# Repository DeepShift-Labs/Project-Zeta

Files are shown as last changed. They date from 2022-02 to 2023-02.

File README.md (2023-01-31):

# Project-Zeta
Github BannerZeta

***This repository is incomplete and under development. There may be mistakes or missing information. Please bear with it. ANY QUESTIONS YOU HAVE CAN BE ASKED IN THE DISCUSSIONS AND ISSUES. Thank you for cooperating.***

The goal of Project Zeta is to develop the world's first General Intelligence. Yes, a robot uprising is coming. We, at Project Zeta, are determined to develop a reliable platform to collect, process, and train data to develop a human-like intelligence. This is possible by using a custom-built, biomimetic, robot dog, with tons of sensors for environmental perception. To learn more about the AI itself, look at this repo:

Readme Card (https://github.com/DeepShift-Labs/MAGIST-Algorithm)

## The Idea
We are making a versatile and cost-effective development platform to collect data. This will allow us to not only collect data but also implement the general intelligence into the robot. In fact, our project MAGIST has achieved General Intelligence! [Check out our other repositories to learn more.](https://github.com/DeepShift-Labs) If you want to brainstorm ideas with us and get the latest updates, make a contribution to our OpenCollective! Check the Links section for the link!

## Setup and Assembly
All assembly instructions will be provided on the Wiki page. The ROS Stack currently requires the "ros-noetic-desktop-full" which has dependencies for around 200 packages. This will only currently work on multi-core PCs and not on Raspberry Pi. This will eventually be optimized to compile on ARM CPUs. More information will be provided on compilation and setup when the code is functional.

## Open Source
The overall point of this project is to make it as open-source as possible. My code is open source, the motors I used also provide their code and all the information to recreate them, and my 3D model of the dog will be on Thingiverse soon. 

- Motors: Lewansoul LX-16A; https://www.hiwonder.com/store/learn/26.html; https://www.amazon.com/Hiwonder-LX-16A-Robotic-Controller-Control/dp/B073XY5NT1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
- Gyroscope: https://www.amazon.com/HiLetgo-MPU-6050-Accelerometer-Gyroscope-Converter/dp/B00LP25V1A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
- Arduino: https://store-usa.arduino.cc/collections/most-popular/products/arduino-mega-2560-rev3

***Note, that the AI might be under a different license. Treat the AI and the robot dog as 2 separate projects.***

### Main Tools
- 3D Printer: https://www.amazon.com/LOTMAXX-Certified-Removable-235x235x280mm-9-25x9-25x11-02inch/dp/B081N6CRVP

## The Team

#### Krishna:
I am a robotics hobbyist, enthusiast, and creator. I have been in robotics for the past 6 years and I have experience in various fields of study. I have tremendous experience in Python, C, Tensorflow, ROS, as well as electronics, 3D Printing, and much more.

## Our AI Project: MAGIST
Readme Card (https://github.com/DeepShift-Labs/MAGIST-Algorithm)

# Links
- OpenCollective: https://opencollective.com/deepshift-labs
- Website: https://deepshift.dev
- Medium: https://deepshiftlabs.medium.com/
- YouTube: https://www.youtube.com/channel/UC6nu2aGbAEX3yy5b0W9GBIg

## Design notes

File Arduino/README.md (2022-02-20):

# Arduino
This contains a complete Arduino code running on the Arduino Mega 2560. Later, I will add hardware and software requirments and compatibility instructions. 

BTW, don't worry about the temp.h file. It is just in place until I put some useless reference code. Don't mind it.

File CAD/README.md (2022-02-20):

# CAD
All the CAD drawing in all te popular formats will be provided. If you are looking for the Gazebo URDF, they are provided in a folder called zeta_description in the ROS_Stack.

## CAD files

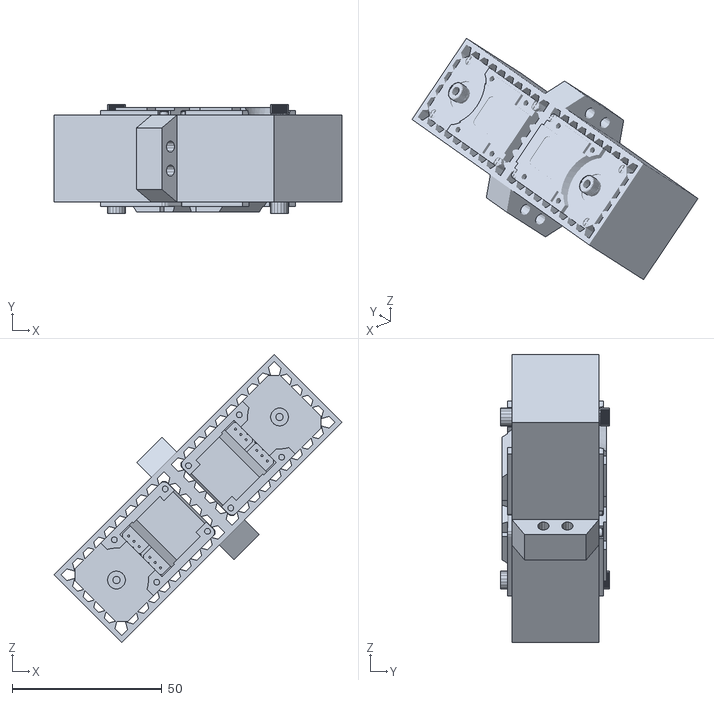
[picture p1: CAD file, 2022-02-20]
ROS_Stack/src/zeta_description/meshes/BR_motor_block_1.stl
96.2 x 36.2 x 96.2

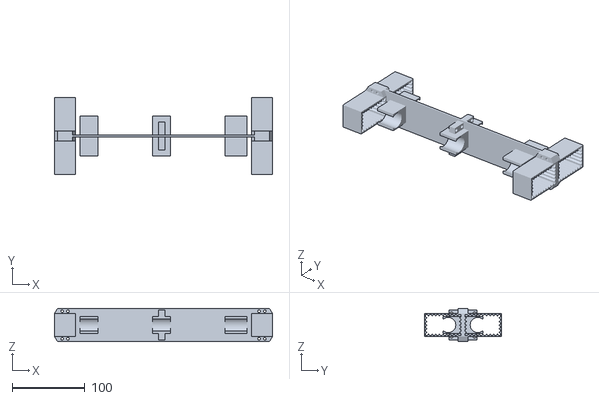
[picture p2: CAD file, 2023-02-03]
ROS_Stack/src/zeta_urdf_description/meshes/base_link.stl
300.0 x 106.4 x 46.0

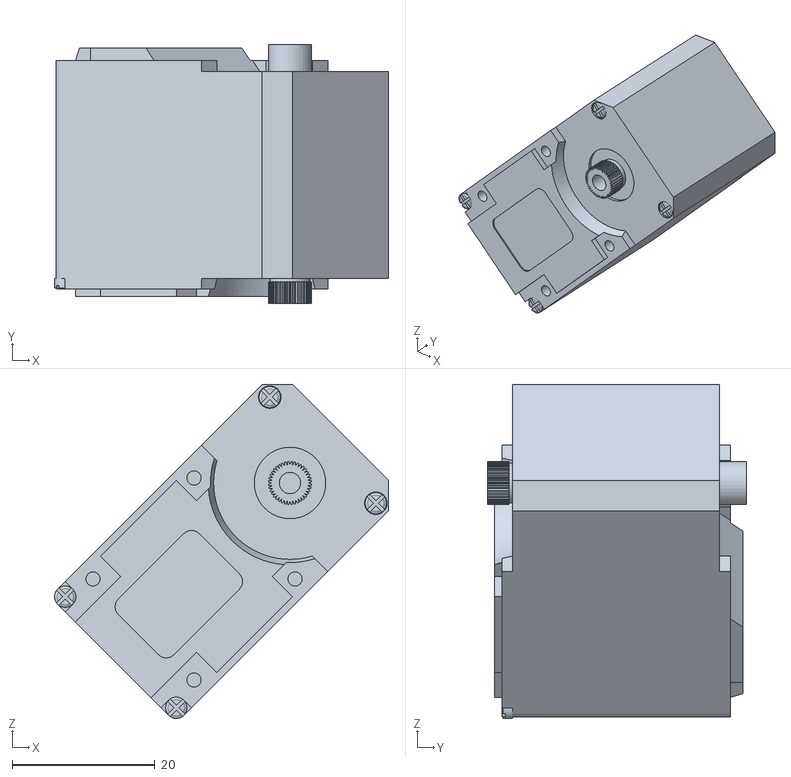
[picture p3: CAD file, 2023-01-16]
URDF/Raw_URDF/zeta_urdf_description_ros1/meshes/FL_2_Motor_1.stl
46.8 x 36.2 x 46.8

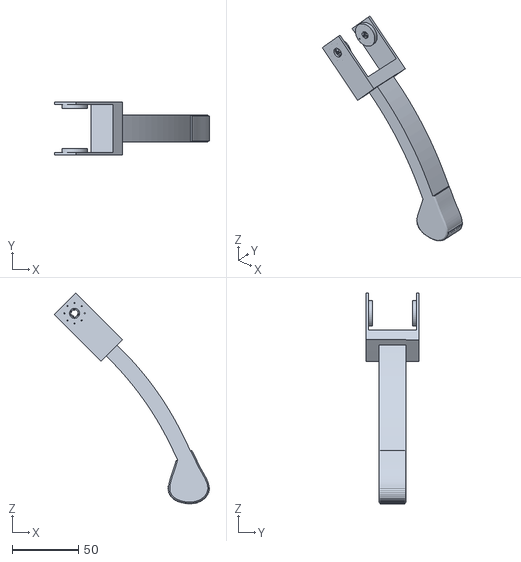
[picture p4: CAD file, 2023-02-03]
URDF/Tuned_URDF/zeta_urdf_description/meshes/BR_Foot_1.stl
117.4 x 40.2 x 159.4

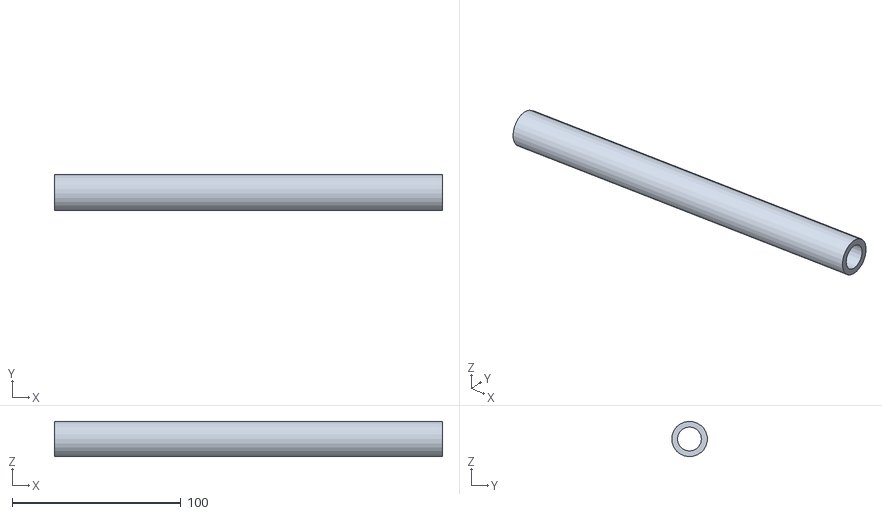
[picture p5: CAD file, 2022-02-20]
ROS_Stack/src/zeta_description/meshes/L_Pipe_1.stl
229.9 x 21.0 x 20.9

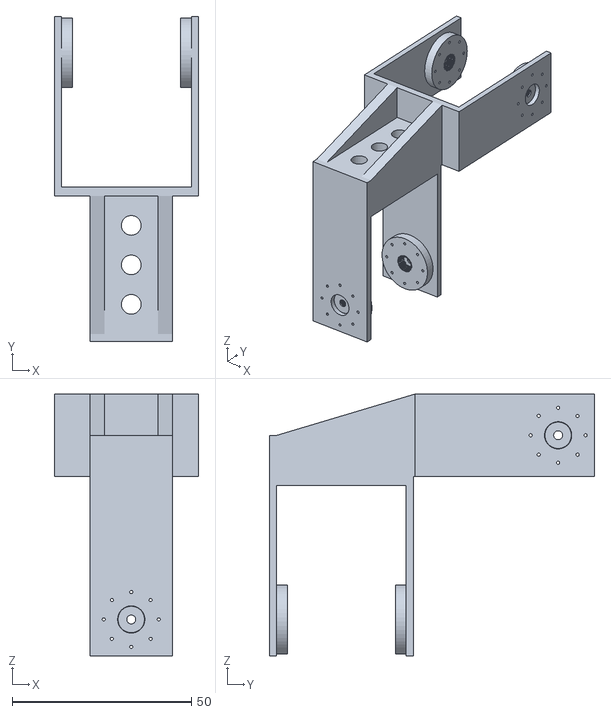
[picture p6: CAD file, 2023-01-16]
URDF/Raw_URDF/zeta_urdf_description_ros1/meshes/FR_Top_Bracket_1.stl
40.2 x 90.6 x 73.0

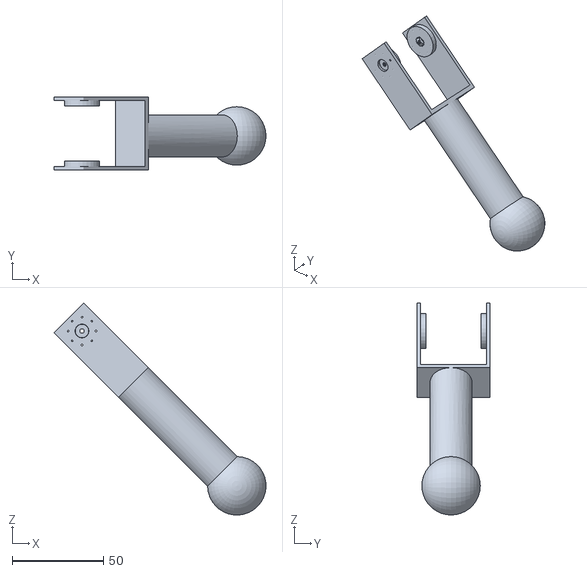
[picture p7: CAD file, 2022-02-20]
ROS_Stack/src/zeta_description/meshes/FL_foot_1.stl
116.0 x 40.2 x 116.0

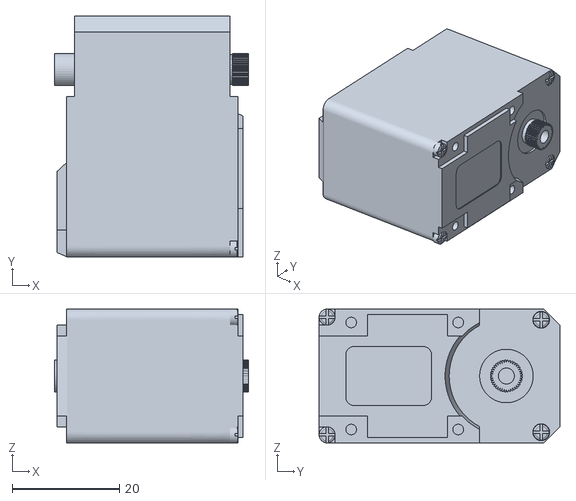
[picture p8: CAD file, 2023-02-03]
ROS_Stack/src/zeta_urdf_description/meshes/FL_3_Motor_1.stl
36.2 x 45.0 x 25.0

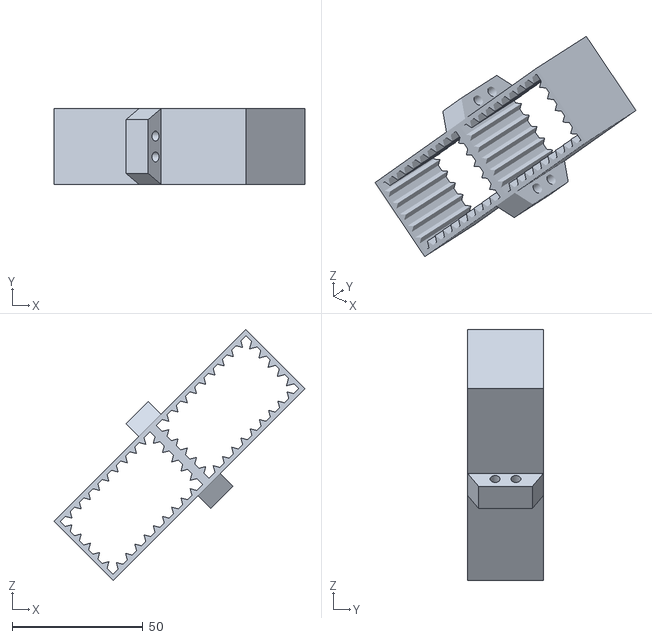
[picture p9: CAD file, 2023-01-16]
URDF/Raw_URDF/zeta_urdf_description_ros2/meshes/FL_Dual_Motor_Mount_1.stl
96.2 x 29.0 x 96.2

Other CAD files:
ROS_Stack/src/zeta_urdf_description/meshes/FR_Foot_1.stl
URDF/Tuned_URDF/zeta_urdf_description/meshes/BR_1_Motor_1.stl
URDF/Raw_URDF/zeta_urdf_description_ros1/meshes/base_link.stl
URDF/Tuned_URDF/zeta_urdf_description/meshes/BR_Top_Bracket_1.stl
ROS_Stack/src/zeta_description/meshes/FL_motor_block_1.stl
ROS_Stack/src/zeta_urdf_description/meshes/BR_Top_Bracket_1.stl
URDF/Raw_URDF/zeta_urdf_description_ros1/meshes/BL_Foot_1.stl
CAD/URDF/zeta_urdf_description/meshes/BL_1_Motor_1.stl
CAD/URDF/zeta_urdf_description/meshes/BL_2_Motor_1.stl
CAD/URDF/zeta_urdf_description/meshes/BL_3_Motor_1.stl
CAD/URDF/zeta_urdf_description/meshes/BL_Dual_Motor_Mount_1.stl
CAD/URDF/zeta_urdf_description/meshes/BL_Foot_1.stl
CAD/URDF/zeta_urdf_description/meshes/BL_Top_Bracket_1.stl
CAD/URDF/zeta_urdf_description/meshes/BR_1_Motor_1.stl
CAD/URDF/zeta_urdf_description/meshes/BR_2_Motor_1.stl
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

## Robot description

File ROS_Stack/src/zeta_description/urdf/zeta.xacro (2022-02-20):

<?xml version="1.0" ?>
<robot name="zeta" xmlns:xacro="http://www.ros.org/wiki/xacro">

<xacro:include filename="$(find zeta_description)/urdf/materials.xacro" />
<xacro:include filename="$(find zeta_description)/urdf/zeta.trans" />

<xacro:include filename="$(find zeta_description)/gazebo/zeta_materials.gazebo" />
<xacro:include filename="$(find zeta_description)/gazebo/zeta_physics.gazebo" />
<xacro:include filename="$(find zeta_description)/gazebo/zeta_plugins.gazebo" />

<link name="base_link">
  <inertial>
    <origin rpy="0 0 0" xyz="-0.14461409332930716 0.0883518788335936 0.2064875843501072"/>
    <mass value="0.26109888559714134"/>
    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
  </inertial>
  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
</link>

<link name="BL_foot_1">
  <inertial>
    <origin rpy="0 0 0" xyz="0.05644955069451385 -0.01619715461445445 -0.056449524198164465"/>
    <mass value="0.050254366168808934"/>
    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
  </inertial>
  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
</link>

<link name="BL_motor_block_1">
  <inertial>
    <origin rpy="0 0 0" xyz="-0.027223152863659228 -0.014672109847305964 -0.02722359848924935"/>
    <mass value="0.08833659369300421"/>
    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
  </inertial>
  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
</link>

<link name="BL_top_1">
  <inertial>
    <origin rpy="0 0 0" xyz="0.016013586630673704 0.047570667286835455 -0.011363799013344889"/>
    <mass value="0.026371988478748627"/>
    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
  </inertial>
  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
</link>

<link name="BR_foot_1">
  <inertial>
    <origin rpy="0 0 0" xyz="0.0564495506979143 0.016196912277002512 -0.05644952420106039"/>
    <mass value="0.050254366173962006"/>
    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
  </inertial>
  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
</link>

<link name="BR_motor_block_1">
  <inertial>
    <origin rpy="0 0 0" xyz="-0.027223152862709155 0.014671867515031146 -0.02722359848963765"/>
    <mass value="0.08833659369327077"/>
    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
  </inertial>
  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
</link>

<link name="BR_top_1">
  <inertial>
    <origin rpy="0 0 0" xyz="0.016013586630497123 -0.04757090961961194 -0.011363799013237114"/>
    <mass value="0.026371988478739887"/>
    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
  </inertial>
  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
</link>

<link name="FR_top_1">
  <inertial>
    <origin rpy="0 0 0" xyz="0.016013586630579342 -0.04757090961960731 -0.011363799013341308"/>
    <mass value="0.026371988478748786"/>
    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
  </inertial>
  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
</link>

<link name="FL_foot_1">
  <inertial>
    <origin rpy="0 0 0" xyz="0.05644955069451409 -0.016197154614456588 -0.056449524198166345"/>
    <mass value="0.0502543661688089"/>
    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
  </inertial>
  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
</link>

<link name="FL_motor_block_1">
  <inertial>
    <origin rpy="0 0 0" xyz="-0.02718553583877841 -0.014671926830458815 -0.027187005197919556"/>
    <mass value="0.08843072327026845"/>
    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
  </inertial>
  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
</link>

<link name="FL_top_1">
  <inertial>
    <origin rpy="0 0 0" xyz="0.0160135866305811 0.04757066728683562 -0.011363799013343834"/>
    <mass value="0.02637198847874842"/>
    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
  </inertial>
  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
</link>

<link name="R_Pipe_1">
  <inertial>
    <origin rpy="0 0 0" xyz="0.1149254583128192 -0.00019701609423813937 -3.9498945669791397e-08"/>
    <mass value="0.06072232848588734"/>
    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
  </inertial>
  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
</link>

<link name="L_Pipe_1">
  <inertial>
    <origin rpy="0 0 0" xyz="0.11492545831281933 0.00019677376152678339 -3.949894572530255e-08"/>
    <mass value="0.06072232848588743"/>
    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
  </inertial>
  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
</link>

<link name="FR_foot_1">
  <inertial>
    <origin rpy="0 0 0" xyz="0.05644955069791327 0.01619691227700047 -0.05644952420106501"/>
    <mass value="0.05025436617396211"/>
    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
  </inertial>
  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
</link>

<link name="FR_motor_block_1">
  <inertial>
    <origin rpy="0 0 0" xyz="-0.027185535838667285 0.014671684498179257 -0.0271870051983098"/>
    <mass value="0.0884307232705417"/>
    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
  </inertial>
  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
</link>

<joint name="Rev46" type="continuous">
  <origin rpy="0 0 0" xyz="-0.054447 0.0 -0.054447"/>
  <parent link="BL_motor_block_1"/>
  <child link="BL_foot_1"/>
  <axis xyz="0.0 1.0 -0.0"/>
</joint>

<joint name="Rev47" type="continuous">
  <origin rpy="0 0 0" xyz="0.0164 0.075469 -0.051319"/>
  <parent link="BL_top_1"/>
  <child link="BL_motor_block_1"/>
  <axis xyz="0.0 -1.0 0.0"/>
</joint>

<joint name="Rev48" type="continuous">
  <origin rpy="0 0 0" xyz="-0.295505 0.128052 0.206491"/>
  <parent link="base_link"/>
  <child link="BL_top_1"/>
  <axis xyz="1.0 -0.0 -0.0"/>
</joint>

<joint name="Rev49" type="continuous">
  <origin rpy="0 0 0" xyz="-0.054447 0.0 -0.054447"/>
  <parent link="BR_motor_block_1"/>
  <child link="BR_foot_1"/>
  <axis xyz="-0.0 -1.0 0.0"/>
</joint>

<joint name="Rev50" type="continuous">
  <origin rpy="0 0 0" xyz="0.0164 -0.075469 -0.051319"/>
  <parent link="BR_top_1"/>
  <child link="BR_motor_block_1"/>
  <axis xyz="-0.0 -1.0 0.0"/>
</joint>

<joint name="Rev51" type="continuous">
  <origin rpy="0 0 0" xyz="-0.295505 0.048652 0.206491"/>
  <parent link="base_link"/>
  <child link="BR_top_1"/>
  <axis xyz="-1.0 0.0 0.0"/>
</joint>

<joint name="Rev54" type="continuous">
  <origin rpy="0 0 0" xyz="-0.024505 0.048652 0.206491"/>
  <parent link="base_link"/>
  <child link="FR_top_1"/>
  <axis xyz="-1.0 0.0 0.0"/>
</joint>

<joint name="Rev55" type="continuous">
  <origin rpy="0 0 0" xyz="-0.054447 0.0 -0.054447"/>
  <parent link="FL_motor_block_1"/>
  <child link="FL_foot_1"/>
  <axis xyz="0.0 -1.0 -0.0"/>
</joint>

<joint name="Rev56" type="continuous">
  <origin rpy="0 0 0" xyz="0.0164 0.075469 -0.051319"/>
  <parent link="FL_top_1"/>
  <child link="FL_motor_block_1"/>
  <axis xyz="0.0 -1.0 0.0"/>
</joint>

<joint name="Rev57" type="continuous">
  <origin rpy="0 0 0" xyz="-0.024505 0.128052 0.206491"/>
  <parent link="base_link"/>
  <child link="FL_top_1"/>
  <axis xyz="1.0 -0.0 -0.0"/>
</joint>

<joint name="Rigid58" type="fixed">
  <origin rpy="0 0 0" xyz="-0.260605 0.067967 0.206491"/>
  <parent link="base_link"/>
  <child link="R_Pipe_1"/>
</joint>

<joint name="Rigid59" type="fixed">
  <origin rpy="0 0 0" xyz="-0.260605 0.108737 0.206491"/>
  <parent link="base_link"/>
  <child link="L_Pipe_1"/>
</joint>

<joint name="Rev61" type="continuous">
  <origin rpy="0 0 0" xyz="-0.054447 0.0 -0.054447"/>
  <parent link="FR_motor_block_1"/>
  <child link="FR_foot_1"/>
  <axis xyz="-0.0 -1.0 0.0"/>
</joint>

<joint name="Rev62" type="continuous">
  <origin rpy="0 0 0" xyz="0.0164 -0.075469 -0.051319"/>
  <parent link="FR_top_1"/>
  <child link="FR_motor_block_1"/>
  <axis xyz="-0.0 -1.0 0.0"/>
</joint>

</robot>

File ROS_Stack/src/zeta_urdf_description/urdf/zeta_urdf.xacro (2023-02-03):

<?xml version="1.0" ?>
<robot name="zeta_urdf" xmlns:xacro="http://www.ros.org/wiki/xacro">

<xacro:include filename="$(find zeta_urdf_description)/urdf/materials.xacro" />
<xacro:include filename="$(find zeta_urdf_description)/urdf/zeta_urdf.trans" />
<xacro:include filename="$(find zeta_urdf_description)/urdf/zeta_urdf.gazebo" />

<link name="dummy">
   </link>

<link name="base_link">
  <inertial>
    <origin xyz="-0.006887732149199177 0.005649968016768892 0.20576830530971255" rpy="0 0 0"/>
    <mass value="0.13102657430451126"/>
    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
  </inertial>
  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
</link>

  <joint name="dummy_joint" type="fixed">
     <parent link="dummy"/>
     <child link="base_link"/>
   </joint>

<link name="FL_Foot_1">
  <inertial>
    <origin xyz="0.05628492645882191 -0.015254964193953696 -0.06460044311982074" rpy="0 0 0"/>
    <mass value="0.10306892931910153"/>
    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
  </inertial>
  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
</link>

<link name="FL_Dual_Motor_Mount_1">
  <inertial>
    <origin xyz="-0.0178564728403042 -8.413959165509688e-08 -0.01785834127628591" rpy="0 0 0"/>
    <mass value="0.023417593270727483"/>
    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
  </inertial>
  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
</link>

<link name="FL_Top_Bracket_1">
  <inertial>
    <origin xyz="0.015262819778462638 0.04757075647002189 -0.011363296083874236" rpy="0 0 0"/>
    <mass value="0.026371988478740775"/>
    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
  </inertial>
  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
</link>

<link name="FR_Top_Bracket_1">
  <inertial>
    <origin xyz="0.015262819778460085 -0.04757082043654881 -0.011363296083875513" rpy="0 0 0"/>
    <mass value="0.02637198847874129"/>
    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
  </inertial>
  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
</link>

<link name="FR_3_Motor_1">
  <inertial>
    <origin xyz="0.0002325331004134623 0.0038811305183252993 5.631524657712106e-08" rpy="0 0 0"/>
    <mass value="0.09250068837166636"/>
    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
  </inertial>
  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
</link>

<link name="Pipe_R_1">
  <inertial>
    <origin xyz="0.11492469146069478 -0.00019692691111165318 4.6343040452367923e-07" rpy="0 0 0"/>
    <mass value="0.060722328485887364"/>
    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
  </inertial>
  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
</link>

<link name="Pipe_L_1">
  <inertial>
    <origin xyz="0.11492469146069506 0.00019686294465318457 4.634304046902127e-07" rpy="0 0 0"/>
    <mass value="0.06072232848588741"/>
    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
  </inertial>
  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
</link>

<link name="BR_3_Motor_1">
  <inertial>
    <origin xyz="0.0002325331007198006 0.0038811305183284427 5.6315247798366386e-08" rpy="0 0 0"/>
    <mass value="0.09250068837166658"/>
    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
  </inertial>
  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
</link>

<link name="BL_3_Motor_1">
  <inertial>
    <origin xyz="0.00023253310072163247 -0.003881194484523093 5.63152473265216e-08" rpy="0 0 0"/>
    <mass value="0.0925006883716665"/>
    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
  </inertial>
  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
</link>

<link name="BR_Top_Bracket_1">
  <inertial>
    <origin xyz="0.015262819778381648 -0.04757082043654326 -0.01136329608387418" rpy="0 0 0"/>
    <mass value="0.026371988478740113"/>
    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
  </inertial>
  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
</link>

<link name="BL_Dual_Motor_Mount_1">
  <inertial>
    <origin xyz="-0.018030919715092797 -8.413958881015038e-08 -0.018031095560186033" rpy="0 0 0"/>
    <mass value="0.02330043804692393"/>
    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
  </inertial>
  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
</link>

<link name="BL_Top_Bracket_1">
  <inertial>
    <origin xyz="0.015262819778382924 0.04757075647002487 -0.011363296083873542" rpy="0 0 0"/>
    <mass value="0.02637198847874093"/>
    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
  </inertial>
  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
</link>

<link name="FL_2_Motor_1">
  <inertial>
    <origin xyz="-0.009461931510561628 -0.015482925779381568 -0.00946268310255663" rpy="0 0 0"/>
    <mass value="0.09250068837133453"/>
    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
  </inertial>
  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
</link>

<link name="FL_1_Motor_1">
  <inertial>
    <origin xyz="0.002744092080384855 -0.00023292577938141545 0.0027444919831759312" rpy="0 0 0"/>
    <mass value="0.09250068837133453"/>
    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
  </inertial>
  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
</link>

<link name="FL_3_Motor_1">
  <inertial>
    <origin xyz="0.00023253310041418396 -0.003881194484526125 5.631524674365451e-08" rpy="0 0 0"/>
    <mass value="0.09250068837166625"/>
    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
  </inertial>
  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
</link>

<link name="BL_2_Motor_1">
  <inertial>
    <origin xyz="-0.009461931511386995 -0.015482925779378778 -0.009462683102555713" rpy="0 0 0"/>
    <mass value="0.09250068837133454"/>
    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
  </inertial>
  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
</link>

<link name="FR_Foot_1">
  <inertial>
    <origin xyz="0.05711390462206373 0.014881645843103392 -0.06555190649851533" rpy="0 0 0"/>
    <mass value="0.10157292595408388"/>
    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
  </inertial>
  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
</link>

<link name="BL_Foot_1">
  <inertial>
    <origin xyz="0.05628492645882055 -0.01525496419395081 -0.06460044311981937" rpy="0 0 0"/>
    <mass value="0.10306892931910108"/>
    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
  </inertial>
  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
</link>

<link name="FR_1_Motor_1">
  <inertial>
    <origin xyz="0.0027440920804559232 0.00023286181312112686 0.002744491982575245" rpy="0 0 0"/>
    <mass value="0.09250068837172258"/>
    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
  </inertial>
  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
</link>

<link name="BR_Foot_1">
  <inertial>
    <origin xyz="0.05628492645881705 0.01525788152098187 -0.06460044311981712" rpy="0 0 0"/>
    <mass value="0.10306892931910183"/>
    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
  </inertial>
  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
</link>

<link name="BL_1_Motor_1">
  <inertial>
    <origin xyz="0.002744092079559113 -0.00023292577937855663 0.002744491983176875" rpy="0 0 0"/>
    <mass value="0.09250068837133459"/>
    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
  </inertial>
  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
</link>

<link name="FR_Dual_Motor_Mount_1">
  <inertial>
    <origin xyz="-0.017856472840306004 2.0173127418532388e-08 -0.017858341276281692" rpy="0 0 0"/>
    <mass value="0.023417593270725956"/>
    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
  </inertial>
  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
</link>

<link name="FR_2_Motor_1">
  <inertial>
    <origin xyz="-0.009461931510641716 0.015482861813120849 -0.009462683103309694" rpy="0 0 0"/>
    <mass value="0.09250068837172218"/>
    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
  </inertial>
  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
</link>
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

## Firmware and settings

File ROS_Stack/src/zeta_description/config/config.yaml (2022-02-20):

simple_model:
  joint_state_controller:
    type: joint_state_controller/JointStateController
    publish_rate: 20

  base_to_second_joint_position_controller:
    type: effort_controllers/JointPositionController
    joint: Rev46
    pid: {p: 1.0, i: 1.0, d: 0.0}

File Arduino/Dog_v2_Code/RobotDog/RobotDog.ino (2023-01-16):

#include <LobotServoController.h>
#include "config.h"
#include "motor_functions.h"
#include "inverse_kinematics.h"
#include "dances.h"

IK_out ik;

void setup() {
  // put your setup code here, to run once:
  Serial.begin(57600);
  Serial1.begin(9600);

  while(!Serial){}
  while(!Serial1){}
//
//  runMotorNormalizeInverse(FL1, 500, time);
//  runMotorNormalizeInverse(FL2, 500, time);
//  runMotorNormalizeInverse(FL3, 500, time);
//
//  runMotorNormalizeInverse(FR1, 500, time);
//  runMotorNormalizeInverse(FR2, 500, time);
//  runMotorNormalizeInverse(FR3, 500, time);
//
//  runMotorNormalizeInverse(BL1, 500, time);
//  runMotorNormalizeInverse(BL2, 500, time);
//  runMotorNormalizeInverse(BL3, 500, time);
//
//  runMotorNormalizeInverse(BR1, 500, time);
//  runMotorNormalizeInverse(BR2, 500, time);
//  runMotorNormalizeInverse(BR3, 500, time);
//
//  delay(time + 1000);
//


  ik = IK_Solver(5, 4, 18);

  runMotorNormalizeInverse(10, degToMotorPos(10, radToDeg(ik.m3)), time);
  
//  runMotorNormalizeInverse(FL2, degToMotorPos(FL2, radToDeg(ik.m2)), time);
//  runMotorNormalizeInverse(FL3, degToMotorPos(FL3, radToDeg(ik.m3)), time);


//  runMotorNormalizeInverse(FL1, degToMotorPos(FL1, radToDeg(ik.m1)), time);
//  runMotorNormalizeInverse(FL2, degToMotorPos(FL2, radToDeg(ik.m2)), time);
//  runMotorNormalizeInverse(FL3, degToMotorPos(FL3, radToDeg(ik.m3)), time);

//  ik = IK_Solver(0, 3, 14);
//  runMotorNormalizeInverse(FR1, degToMotorPos(FR1, radToDeg(ik.m1)), time);
//  runMotorNormalizeInverse(FR2, degToMotorPos(FR2, radToDeg(ik.m2)), time);
//  runMotorNormalizeInverse(FR3, degToMotorPos(FR3, radToDeg(ik.m3)), time);
//
//  ik = IK_Solver(0, 3, 14);
//  runMotorNormalizeInverse(BL1, degToMotorPos(BL1, radToDeg(ik.m1)), time);
//  runMotorNormalizeInverse(BL2, degToMotorPos(BL2, radToDeg(ik.m2)), time);
//  runMotorNormalizeInverse(BL3, degToMotorPos(BL3, radToDeg(ik.m3)), time);
//
//  ik = IK_Solver(0, 3, 14);
//  runMotorNormalizeInverse(BR1, degToMotorPos(BR1, radToDeg(ik.m1)), time);
//  runMotorNormalizeInverse(BR2, degToMotorPos(BR2, radToDeg(ik.m2)), time);
//  runMotorNormalizeInverse(BR3, degToMotorPos(BR3, radToDeg(ik.m3)), time);
  delay(time + 50);
Serial.println("EXIT");

}

void loop() {

}

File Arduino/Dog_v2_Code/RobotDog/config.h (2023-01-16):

// Motor ID definitions
//FL1 - Front-Left-1
//1 - Foot; 2 - Knee; 3 - Hip
#define FL1 1
#define FL2 12
#define FL3 3
#define FR1 11
#define FR2 10
#define FR3 2
#define BL1 5
#define BL2 6
#define BL3 4
#define BR1 7
#define BR2 9
#define BR3 8
//End of  motor ID definitions

#define Debug 1 //Enable Debug

LobotServoController Controller(Serial1); // Create Servo Controller Object

float upper_leg_length = 8; //Leg length in cm for IK
float lower_leg_length = 13; //Leg length in cm for IK

const int time = 1000; //Time per motor move command

//MAX Definitions
const int motor_1_MIN = 320;
const int motor_1_MAX = 1000;

const int motor_2_MIN = 320;
const int motor_2_MAX = 870;

const int motor_3_MIN = 0;
const int motor_3_MAX = 750;

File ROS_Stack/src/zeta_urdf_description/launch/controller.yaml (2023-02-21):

zeta_urdf:
  # Publish all joint states -----------------------------------
  joint_state_controller:
    type: joint_state_controller/JointStateController
    publish_rate: 50

  # Position Controllers --------------------------------------
  FL_1_position_controller:
    type: effort_controllers/JointPositionController  
    joint: FL_1
    pid: {p: 9, i: 0.03, d: 0.3055, i_clamp_min:  -1000, i_clamp_max: 1000}
  FL_3_position_controller:
    type: effort_controllers/JointPositionController
    joint: FL_3
    pid: {p: 9, i: 0.03, d: 0.3055, i_clamp_min:  -1000, i_clamp_max: 1000}
  FR_3_position_controller:
    type: effort_controllers/JointPositionController
    joint: FR_3
    pid: {p: 9, i: 0.03, d: 0.3055, i_clamp_min:  -1000, i_clamp_max: 1000}
  BR_3_position_controller:
    type: effort_controllers/JointPositionController
    joint: BR_3
    pid: {p: 9, i: 0.03, d: 0.3055, i_clamp_min:  -1000, i_clamp_max: 1000}
  BL_3_position_controller:
    type: effort_controllers/JointPositionController
    joint: BL_3
    pid: {p: 9, i: 0.03, d: 0.3055, i_clamp_min:  -1000, i_clamp_max: 1000}
  FL_2_position_controller:
    type: effort_controllers/JointPositionController
    joint: FL_2
    pid: {p: 9, i: 0.03, d: 0.3055, i_clamp_min:  -1000, i_clamp_max: 1000}
  BL_2_position_controller:
    type: effort_controllers/JointPositionController
    joint: BL_2
    pid: {p: 9, i: 0.03, d: 0.3055, i_clamp_min:  -1000, i_clamp_max: 1000}
  FR_1_position_controller:
    type: effort_controllers/JointPositionController
    joint: FR_1
    pid: {p: 9, i: 0.03, d: 0.3055, i_clamp_min:  -1000, i_clamp_max: 1000}
  BL_1_position_controller:
    type: effort_controllers/JointPositionController
    joint: BL_1
    pid: {p: 9, i: 0.03, d: 0.3055, i_clamp_min:  -1000, i_clamp_max: 1000}
  BR_1_position_controller:
    type: effort_controllers/JointPositionController
    joint: BR_1
    pid: {p: 9, i: 0.03, d: 0.3055, i_clamp_min:  -1000, i_clamp_max: 1000}
  FR_2_position_controller:
    type: effort_controllers/JointPositionController
    joint: FR_2
    pid: {p: 9, i: 0.03, d: 0.3055, i_clamp_min:  -1000, i_clamp_max: 1000}
  BR_2_position_controller:
    type: effort_controllers/JointPositionController
    joint: BR_2
    pid: {p: 9, i: 0.03, d: 0.3055, i_clamp_min:  -1000, i_clamp_max: 1000}

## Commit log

2021-10-11 Initial Arduino commit!
2021-10-18 Added inverse commands for all legs; IK working on all 4 legs
2021-10-25 Working gait without suspension; still wobbles
    [Project-Zeta_main.ino]
2021-10-25 Working gait; no wobble, no load issue
    [Project-Zeta_main.ino, config.h, functions.h]
2021-11-23 New Gait with 2 leg motion
    This gait can do 2 legs at a time and properly lift them up.
2021-11-23 Speed and Wobble
    Marginally reduced wobble and upped the speed
    [Project-Zeta_main.ino, config.h]
2021-11-23 Decreased Wobble
    The legs now touch the ground
    [Project-Zeta_main.ino]
2021-12-25 Initial Models
    Made initial model. Lots of issues.
    [Zeta v2.3mf]
2022-01-01 Fixed Issues with motor cup. Added more detail.
    [Zeta v2.3mf]
2022-01-03 Initial URDF and Gazebo
    Basic gazebo, robot controller, and urdf running
    [BL_foot_1.stl, BL_motor_block_1.stl, BL_top_1.stl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]
2022-01-03 Added URDF and Gazebo Package to New Workspace
    [BL_foot_1.stl, BL_motor_block_1.stl, BL_top_1.stl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]
2022-01-03 Updated Rev46 Joint
2022-01-03 New URDF With Labels
    1 - bottom; 2 - middle; 3 - top
    BL - Back-Left
    FR - Front-Right
    [controller.yaml, zeta.xacro]
2022-01-03 Fixed Issue with Joint Controller
    [zeta.xacro]
2022-01-03 Added all joints
2022-01-03 Modified physics constants
    Changed mass
    [zeta_BAK.xacro]
2022-01-08 Uploaded URDF F3D for Question
2022-01-08 Added URDF and Compacted .f3d with Joint
    [BL_1_Motor_1.stl, BL_2_Motor_1.stl, BL_3_Motor_1.stl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]
2022-01-09 New URDF
    Better physics but everything breaks in gazebo :(
    [BL_1_Motor_1.stl, BL_2_Motor_1.stl, BL_3_Motor_1.stl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]
2022-01-23 Updated URDF but Still Breaks
    Changes some parameters but the whole robot still breaks. But only the number 3 joints break
    [controller.yaml, zeta_urdf.xacro]
2022-02-20 Arduino and CAD directories commit
    [BL_1_Motor_1.stl, BL_2_Motor_1.stl, BL_3_Motor_1.stl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]
2022-02-20 Merging Featrure 2-Leg-Gait into main
2022-02-20 Tuned joint offset
2022-02-20 Started 2 leg gait
2022-02-22 updated kinematics service
2022-02-26 Added motor control lib
2022-03-04 motor function stack added
2023-01-16 New working URDF from @SpaceMaster85 exporter
    [BL_1_Motor_1.stl, BL_2_Motor_1.stl, BL_3_Motor_1.stl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]
2023-01-16 Added ROS1 and ROS2 URDFs with Physical Materials closer to reality
    [BL_1_Motor_1.stl, BL_2_Motor_1.stl, BL_3_Motor_1.stl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]
2023-02-02 Working and controllable URDF
    Fixed joint problems! The PID gains were too high and it wasn't using sim_time in gazebo.launch. Tuned PID to work. Manually found joint limits.
    [BL_1_Motor_1.stl, BL_2_Motor_1.stl, BL_3_Motor_1.stl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]
2023-02-03 New URDF with Pi and Arduino
    Added inertia using the script and modified PID to provide more power. Problem: Simulations seems to be in slow motion.
    [ArduinoMega_STEP_AP203_v1_1.stl, Arduino_Mount_v1_1.stl, BL_1_Motor_1.stl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]
2023-02-03 Started work on motor controller
    Made a motor publisher array.
2023-02-21 Clean up URDF and add I clamp
    This fixed the weird spider dance issue
    [controller (copy).yaml, zeta_urdf (copy).xacro]
2023-02-21 Remove DEPRECATED that cause make error
    [BL_1_Motor_1.stl, BL_2_Motor_1.stl, BL_3_Motor_1.stl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]
2023-02-21 Update tuned URDF to have new I clamp in the URDF folder
    [ArduinoMega_STEP_AP203_v1_1.stl, Arduino_Mount_v1_1.stl, BL_1_Motor_1.stl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]
2023-02-21 Added simple action server for motor emulator
2023-02-22 Added client and joint motion works.
2025-03-16 modified everything?
    [controller (copy).yaml, controller.yaml]
